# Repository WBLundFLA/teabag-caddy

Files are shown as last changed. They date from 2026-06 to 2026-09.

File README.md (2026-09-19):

# Teabag Caddy

OpenSCAD design for a 3x4 tea bag drawer organiser. Bags sit vertically, tags visible,
U-shaped finger cutouts make grabbing easy.
Part of the Wabble 3D capability fleet, governed by `WBLundFLA/wabble-print-capabilities`.

## Design

- **Grid:** 3 columns x 4 rows (12 cells), ~70 x 70mm each
- **Overall:** 220 x 296 x 70mm assembled
- **Split:** Two identical 220 x 148mm halves joined by a 2+1 tongue-and-groove joint
- **Bed requirement:** Each half fits a 235x235mm bed (Sovol SV06, Ender 3, etc.)
- **Walls:** Solid front/back with U finger cutouts; diamond lattice sides
- **Material:** PLA, ~110-130g per half

## Files

| File | Purpose |
|---|---|
| `files/caddy_front.scad` | Front half -- open in OpenSCAD, F6, export STL |
| `files/caddy_back.scad` | Back half -- same workflow |
| `files/caddy_preview.scad` | Both halves assembled for visual check |
| `files/caddy_params.scad` | All parameters -- edit this to customise |
| `files/lattice_wall.scad` | Lattice wall modules (dependency, do not edit) |

## Print settings

- Layer height: 0.2mm
- Perimeters: 3
- Infill: 15%
- Supports: none
- Brim: recommended for the first half

## Assembly

The two halves slot together along the long edge. The front half has two tongues and
one centre groove; the back half has two grooves and one centre tongue. Press together
until the tongues click home. No glue needed -- the drawer walls hold them in place.

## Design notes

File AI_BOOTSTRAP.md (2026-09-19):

# AI Bootstrap: teabag-caddy

Part of the WBLundFLA 3D printing capability fleet.
Parametric interlocking CAD models in OpenSCAD adhering to **Wabble Standard Operating Procedures (WSOP)**.

## Core Directives

1. **The Holster Rule (Authorizations):**
   - You are fully authorized to read, inspect, diff, and test code.
   - NEVER push to remote, alter running production services, or overwrite deployed assets without explicit human consent.
2. **Centralized Slicing & Profiles:**
   - Canonical printer profiles and centralized headless slicing logic reside in `WBLundFLA/wabble-print-capabilities`.
   - Florida Sovol SV06 profile: `printers/william-sovol-sv06.json` (build envelope 220×220, direct drive, PEI spring steel).
   - Slicing stack: `slicer/sovol-sv06/` in `wabble-print-capabilities`.
3. **The Centauri Secret Rule:**
   - NEVER commit or log printer LAN IP addresses, access codes, or credentials.
4. **Physical Safety & Slicing:**
   - Slicing and dispatch automation must set `select=true, print=false`. Never start a thermal heater or stepper motors unattended.

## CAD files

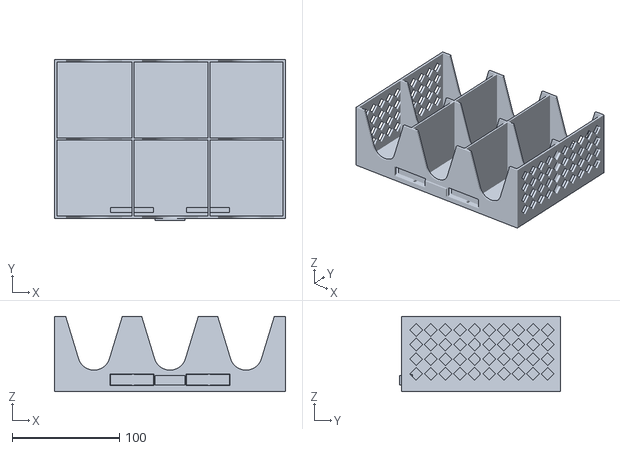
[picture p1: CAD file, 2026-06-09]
files/caddy_back.stl
215.0 x 150.0 x 70.0

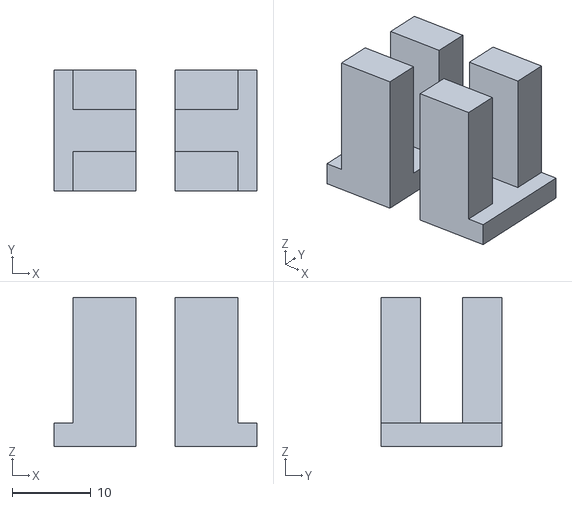
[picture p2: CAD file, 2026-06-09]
files/caddy_clip.stl
25.8 x 15.4 x 19.0

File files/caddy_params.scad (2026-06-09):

use <lattice_wall.scad>

// --- Overall dimensions ---
total_w = 215;
half_d  = 148;
wall_h  = 70;
cols    = 3;
rows    = 2;
ow      = 2.4;    // outer wall thickness
dt      = 2.0;    // divider thickness
bt      = 3.0;    // base thickness

cell_w = (total_w - 2*ow - (cols-1)*dt) / cols;
cell_d = (half_d  - 2*ow - dt) / rows;

// --- Lattice (side walls only) ---
lat_gap    = 12;
lat_strand = 1.6;

// --- Finger-cutout geometry ---
// Profile Y=0 is arc centre; arc dips to Y=-uc_bot_w/2.
// uc_z_off maps profile-Y to world-Z: world-Z = profile-Y + uc_z_off
//   arc bottom  world-Z = uc_z_off - uc_bot_w/2 = 35 - 15 = 20 mm
//   top of profile world-Z = 35 + 40 = 75 > wall_h = 70 (guaranteed open)
uc_bot_w = 30;    // bottom semicircle diameter
uc_top_w = 36;    // distance between top-corner circle centres
uc_cr    = 8;     // top-corner circle radius (also controls how far above wall the cut exits)
uc_z_off = 35;    // Z offset: arc bottom lands at Z = uc_z_off - uc_bot_w/2 = 20

// Profile-Y at wall top (world-Z = wall_h = 70)
uc_y_wt  = wall_h - uc_z_off;   // = 35

// --- Tongue/groove joint ---
tl  = 40;
th  = 10;
tt  = 5;
tol = 0.5;

// Back half centre tongue — sized to fit as-printed front groove (30mm wide, 11mm tall, ~2.5mm deep)
tl_c = 28;   // 1mm clearance each side of 30mm opening
th_c = 9;    // 1mm clearance each side of 11mm opening
tt_c = 2;    // conservative fit for ~2.5mm groove depth

function ccx(i) = ow + i*(cell_w + dt) + cell_w/2;

tx1 = ow + cell_w + dt/2;
tx2 = ow + 2*(cell_w + dt) - dt/2;
tx_c = total_w / 2;

// --- 2-D U-profile ---
// Hull of bottom half-circle + two side circles at wall-top level.
// The side circles are centred at (+-uc_top_w/2, uc_y_wt) -- IN the solid
// wall material -- so the hull curve sweeps smoothly from solid into U.
// Profile is widest at uc_y_wt (wall top) and tapers down to uc_bot_w.
// Circles reach Y = uc_y_wt + uc_cr = 43, mapping to world-Z = 78 > 70
// so the cut is guaranteed to break through the wall top with no hard edge.
module u_profile_2d() {
    hull() {
        // Bottom half-circle (dips below Y=0)
        intersection() {
            circle(r = uc_bot_w/2, $fn = 64);
            translate([-(uc_bot_w/2 + 1), -uc_bot_w])
                square([uc_bot_w + 2, uc_bot_w]);
        }
        // Top-corner circles: centres in solid wall, arcs sweep into U
        translate([ uc_top_w/2, uc_y_wt]) circle(r = uc_cr, $fn = 32);
        translate([-uc_top_w/2, uc_y_wt]) circle(r = uc_cr, $fn = 32);
    }
}

// --- 3-D cutout through wall of thickness wt ---
module u_cut(wt) {
    translate([0, wt + 0.1, uc_z_off])
        rotate([90, 0, 0])
            linear_extrude(wt + 0.2)
                u_profile_2d();
}

// --- Half-tray ---
// Front/back walls: SOLID (U cutouts print better in solid walls)
// Side walls: lattice (no cutouts, decorative/lightweight)
// 2+1 tongue scheme:
//   Front: 2 tongues (tx1,tx2) + 1 centre groove
//   Back:  2 grooves (tx1,tx2) + 1 centre tongue
module caddy_half(is_front = true) {
    wy_back = half_d - ow;
    wy_div  = ow + cell_d;

    difference() {
        union() {
            // Base
            cube([total_w, half_d, bt]);
            // Front outer wall -- SOLID
            translate([0, 0, bt])
                cube([total_w, ow, wall_h - bt]);
            // Back outer wall -- SOLID
            translate([0, wy_back, bt])
                cube([total_w, ow, wall_h - bt]);
            // Left side wall -- LATTICE
            translate([0, 0, bt])
                lattice_wall_y(half_d, wall_h - bt, ow, lat_gap, lat_strand);
            // Right side wall -- LATTICE
            translate([total_w - ow, 0, bt])
                lattice_wall_y(half_d, wall_h - bt, ow, lat_gap, lat_strand);
            // Vertical column dividers (solid)
            for (i = [1 : cols-1])
                translate([ow + i*(cell_w + dt) - dt/2, ow, bt])
                    cube([dt, half_d - 2*ow, wall_h - bt]);
            // Horizontal row divider (solid)
            translate([ow, wy_div, bt])
                cube([total_w - 2*ow, dt, wall_h - bt]);

            // Joint geometry
            if (is_front) {
                translate([tx1 - tl/2, half_d,         bt+3]) cube([tl, tt,    th]);
                translate([tx2 - tl/2, half_d,         bt+3]) cube([tl, tt,    th]);
                translate([tx_c - tl/2, half_d - tt*2, bt+3]) cube([tl, tt*2,  th]);
            } else {
                translate([tx1 - tl/2, 0, bt+3]) cube([tl, tt*2, th]);
                translate([tx2 - tl/2, 0, bt+3]) cube([tl, tt*2, th]);
                translate([tx_c - tl_c/2, -tt_c, bt+3]) cube([tl_c, tt_c, th_c]);
            }
        }

        // U cutouts
        for (i = [0 : cols-1]) translate([ccx(i), 0,       0]) u_cut(ow);
        for (i = [0 : cols-1]) translate([ccx(i), wy_back, 0]) u_cut(ow);
        for (i = [0 : cols-1]) translate([ccx(i), wy_div,  0]) u_cut(dt);

        // Groove cuts
        if (is_front) {
            translate([tx_c - tl/2 - tol, half_d - tt - tol, bt+3 - tol])
                cube([tl + 2*tol, tt + tol + 0.1, th + 2*tol]);
        } else {
            translate([tx1 - tl/2 - tol, -0.1, bt+3 - tol])
                cube([tl + 2*tol, tt + tol, th + 2*tol]);
            translate([tx2 - tl/2 - tol, -0.1, bt+3 - tol])
                cube([tl + 2*tol, tt + tol, th + 2*tol]);
        }
    }
}

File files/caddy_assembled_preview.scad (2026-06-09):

// Both halves shown side-by-side with 5mm gap — visual inspection only, do NOT print
include <caddy_params.scad>

caddy_half(is_front = true);
translate([0, half_d + 5, 0])
    caddy_half(is_front = false);

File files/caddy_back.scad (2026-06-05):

// ============================================================
//  caddy_back.scad  —  BACK HALF (far side of drawer)
//  Render: F6   Export: File → Export → STL → caddy_back.stl
// ============================================================
include <caddy_params.scad>

caddy_half(is_front = false);

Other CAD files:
files/caddy_front.stl
files/caddy_clip.scad
files/caddy_clip_context.scad
files/caddy_front.scad
files/caddy_preview.scad
files/joint_back.scad
files/joint_preview.scad
files/joint_test.scad
files/lattice_wall.scad

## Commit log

2026-06-05 Initial commit: teabag caddy 3x4 OpenSCAD design
    Two interlocking 3x2 halves (220x148mm each) for Sovol SV06.
    Diamond lattice outer walls, solid dividers, tongue/groove joint,
    smooth flared U finger cutouts.
    [caddy_back.scad, caddy_front.scad, caddy_params.scad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]
2026-06-05 Fix caddy_params: ASCII-only comments, hull() U cutout
    Remove non-ASCII box-drawing chars (parser breaks).
    Rebuild u_profile_2d as hull() of bottom half-circle + wide top
    line -- smooth flared U with no sharp notches, 50mm visible depth.
    [caddy_params.scad]
2026-06-05 Fix lattice side walls, loosen tongue tolerance, add 2+1 joint
    - lattice_wall_y: fix rotate axis (45,0,0) for diamond pattern in YZ
    - tol: 0.3 -> 0.5mm (tongue was too tight to assemble)
    - 2+1 tongue scheme: front gets 2 tongues + 1 centre groove,
    back gets 2 grooves + 1 centre reverse tongue
    [caddy_params.scad, lattice_wall.scad]
2026-06-05 Fix lattice: centre cut in wall so diamonds pierce all the way through
    Was: translate Y=-0.1 with Y-extent thick+0.2 = only reached halfway
    Fix: translate Y=thick/2, Y-extent thick+0.4 = guaranteed full penetration
    [lattice_wall.scad]
2026-06-05 Solid front/back walls, concave U top corners
    Front and back walls changed from lattice to solid -- lattice plus
    U cutouts in thin walls caused print failures. Side walls keep lattice.
    U profile top corners now have concave fillets: arc centre is in
    solid wall material so the curve sweeps from solid into the opening.
    [caddy_params.scad]
2026-06-05 Fix U top corners: hull of circles replaces horn-causing fillets
    Previous approach (corner square minus arc) created pointed spikes.
    New: hull() of bottom half-circle + two side circles centred at wall-top
    level in the solid wall. Arc naturally sweeps from solid into U opening,
    widest at wall top, no corners anywhere.
    [caddy_params.scad]
2026-06-07 Add README.md and CLAUDE.md
    README: project overview, file table, print settings, assembly notes.
    CLAUDE.md: project context, hard rules, key parameters for AI-assisted sessions.
2026-06-07 Add PrusaSlicer config template for Sovol SV06 + OctoPrint
    Includes print profile (0.2mm/3 perimeters/15% infill/no supports),
    filament (PLA 215C/60C bed), printer, and OctoPrint physical printer
    pointing at https://octoprint.wblsoft. API key kept in gitignored
    teabag-caddy.ini; copy from .template and fill in key to use.
2026-06-07 Fix: use printhost_apikey (not apikey) in slicer template
    PrusaSlicer physical printer ini uses printhost_apikey; the
    slice-and-upload script in cub-cadet-cc30h-mods reads that key.
2026-06-07 Add exported STLs for caddy front and back halves
    [caddy_back.stl, caddy_front.stl]
2026-06-09 Add seam bridge clips; fix back centre tongue and STL width
    - caddy_clip.scad/.stl: new bridge clip design -- bridge overhangs outer
    side wall top, legs hang inside corner gripping both seam walls (5.4mm
    Y-slot over combined 4.8mm seam wall). Replaces abandoned T-clip design
    which had geometric conflict with side wall material.
    - caddy_params.scad: back centre tongue sized to as-printed front groove
    (tl_c=28, th_c=9, tt_c=2); total_w corrected to 215mm
    - caddy_front/back.stl: re-exported at correct 215mm width
    - caddy_assembled_preview.scad: both halves with 5mm gap for visual check
    - caddy_clip_context.scad: clip shown in installed position on seam corner
    - joint_preview.scad: joint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
    [caddy_assembled_preview.scad, caddy_back.stl, caddy_clip.scad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]
2026-09-19 docs: align with WSOP standards and wabble-print-capabilities fleet hub
